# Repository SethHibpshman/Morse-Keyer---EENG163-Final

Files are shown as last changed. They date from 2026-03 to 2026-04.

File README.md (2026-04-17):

# Iambic Morse Keyer & Trainer

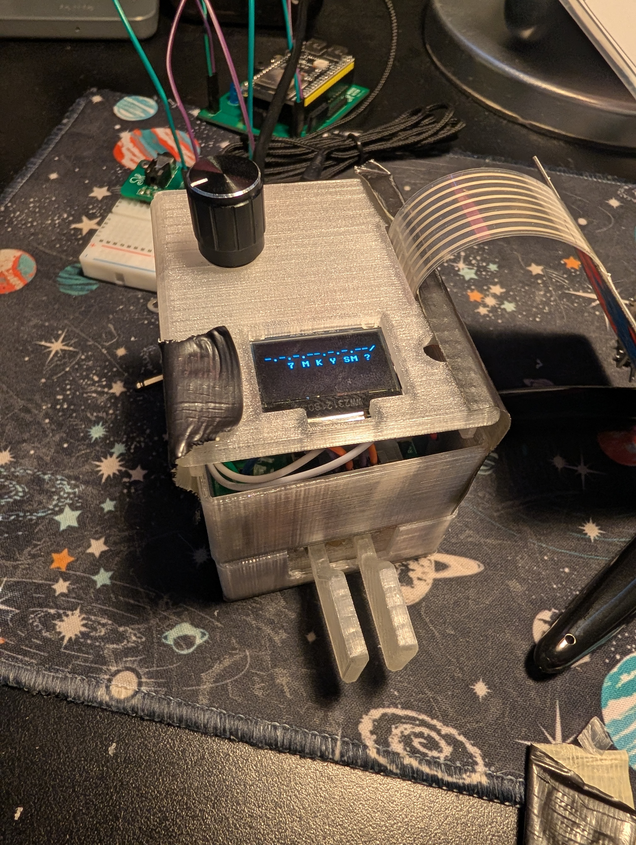
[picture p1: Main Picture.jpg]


A standalone, feature-rich Morse code keyer and trainer built on the ESP32-S3 running MicroPython. Designed as a hands-on embedded systems project covering real-time signal generation, hardware input handling, OLED display, settings menus, multi-mode keying, automatic decoding, and inter-device communication.

## Demo Video

See it [here](https://youtu.be/7UfE0N1uJJo)!

## Features

- **Four keying modes** — Iambic A, Iambic B, Ultimatic, and Straight Key
- **Real-time morse decoding** — automatically decodes keyed input to text on the OLED
- **Rotary encoder settings menu** — scroll and edit WPM, volume, LED, decoding toggle, and keying mode
- **Keyboard Replay Mode** — T9-style multi-tap keypad input encodes text to morse and plays it back
- **Automatic letter and word spacing** — gap detection scales with WPM setting
- **Sleep mode with screensaver** — bouncing logo after 60 seconds of inactivity
- **Boot screen** — typewriter-style startup sequence
- **Debug mode** — live paddle state, encoder pins, keypad input, and memory readout
- **UART communication** — transmits morse content to an STM32 relay display over serial

## Hardware

| Component | Details |
|---|---|
| Microcontroller | ESP32-S3 |
| Display | SSD1306 128x64 OLED (SoftI2C) |
| Paddles | 2x momentary buttons (Dit / Dah) |
| Keypad | 4x4 membrane matrix keypad |
| Rotary Encoder | CLK, DT, SW with long-press menu activation |
| Buzzer | Piezo PWM buzzer |
| LED | Single external indicator LED |
| Communication | UART1 to STM32 relay at 115200 baud |

## Pin Mapping

| Pin | Function |
|---|---|
| 7 | Dit paddle |
| 16 | Dah paddle |
| 38 | Buzzer (PWM) |
| 1 | External LED |
| 4 | Rotary CLK |
| 47 | Rotary DT |
| 45 | Rotary SW |
| 46 | OLED SCL |
| 8 | OLED SDA |
| 17 | UART TX |
| 18 | UART RX |
| 5, 6, 15, 17 | Keypad rows |
| 18, 2, 39, 40 | Keypad columns |

## PCB Design

Designed in KiCad. Project files available in [`/PCB Design - KiCad Program/ESP32 Board`](PCB%20Design%20-%20KiCad%20Program/ESP32%20Board).

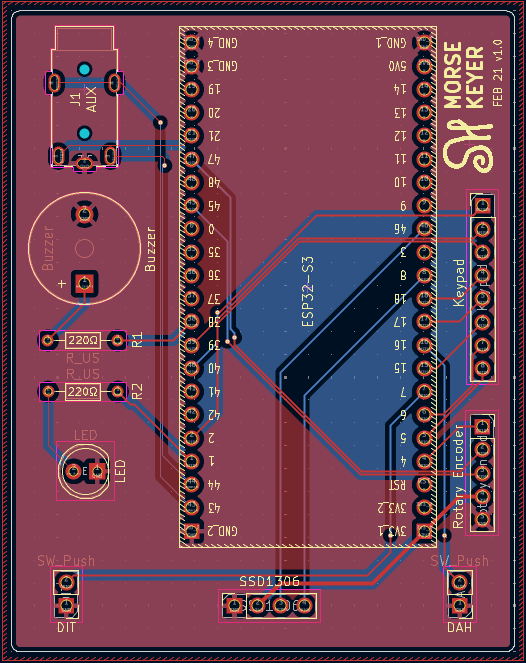
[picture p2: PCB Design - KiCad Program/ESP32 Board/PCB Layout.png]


## Software

Written entirely in **MicroPython**.

**Dependencies:**
- `ssd1306` — OLED driver
- `gfx` — OLED graphics primitives
- `keypad` — 4x4 matrix keypad driver
- `urandom` — screensaver randomization

## Project Structure

```
main.py          # Full application — hardware init, all functions, main loop
```

## Settings Menu

Hold the rotary encoder button for 2 seconds to open the settings menu. Short press to enter edit mode on a selected item. Rotate to scroll or adjust values.

| Setting | Options |
|---|---|
| Mode | Sandbox, Training, Keyboard Replay, Telegraph, Debug |
| Keying Mode | Iambic A, Iambic B, Ultimatic, Straight Key |
| Volume | 0 – 10 |
| LED | Enabled / Disabled |
| Decoding | Enabled / Disabled |
| About | Scrolling credits page |
| Reset | Hard resets the device |

## Keying Modes

| Mode | Behavior |
|---|---|
| **Iambic A** | Alternates dit/dah while both paddles held; stops on release |
| **Iambic B** | Same as A but sends one extra element after both paddles are released |
| **Ultimatic** | Last-pressed paddle wins when both are held simultaneously |
| **Straight Key** | Either paddle held produces a continuous tone |

## Morse Decoding

Gap detection runs automatically. After a paddle idle period equal to 3x the dit duration, a letter space is inserted and the last morse sequence is decoded. After 7x the dit duration, the space is upgraded to a word break. All thresholds scale with the live WPM setting.

## Keyboard Replay Mode

Enter text using the 4x4 keypad with T9-style multi-tap input (phone keyboard layout). The device encodes the typed text to morse in real time and displays it on the OLED. Press **B** to play the encoded sequence through the buzzer.

| Key | Control Action |
|---|---|
| A | Backspace |
| B | Play current text as morse |

## UART / STM32 Integration

In Telegraph mode, the device transmits the current morse string over UART1 as a UTF-8 newline-terminated message on each loop tick. A companion STM32 device running a separate display driver receives and renders the last 20 characters on an ILI9341 LCD.

## Cost

| Item | Qty | Unit | Total |
| --- | --- | --- | --- |
| ESP32-S3 Dev Board | 1 | $12.00 | $12.00 |
| Push Buttons (momentary) | 3 | $0.05  | $0.15 |
| Piezo Buzzer | 1 | $1.00  | $1.00 |
| LED | 1 | $0.03  | $0.03 |
| Resistors, wires, protoboard | — | — | $5.00 |
| SSD1306 OLED 128x64 | 1 | $3.00  | $3.00 |
| Rotary Encoder | 1 | $3.00  | $3.00 |
| 4x4 Membrane Keypad | 1 | $5.00  | $5.00 |
| PCBs (x1) | 1 | — | $5.00 |
| 3D-printed enclosure | 1 | — | $0.00 |
| STM32 Microcontroller (borrowed) | 1 | $0.00  | $0.00 |
| Aux ports / cables | — | — | $13.00 |
| 2nd ESP32 node (full duplicate)  | — | — | $29.13 |
| Microphone / analog input | 1 | $3.00  | $3.00 |
| Misc analog sensors | 1 | $2.00  | $2.00 |
| **Hardware Total** | | | **$81.34** |
| Software | — | — | $0.00 |
| Tools | — | — | $0 – $30 |
| **Grand Total** | | | **~$81 – $111** |

> **Notes:**
> - Unit costs reflect bulk purchasing; individual retail prices can be significantly higher.
> - Some components were salvaged or borrowed; actual cost may be lower.
> - 3D printing assumes university or personal printer access. Outsourced printing would add to the total.
> - PCB cost assumes overseas fabrication. Any revision spins add another ~$15 per run.
## Author

**Seth Hibpshman**
Student of Electrical Engineering — Eastern Washington University
EENG 163: Introduction to Embedded Systems

## License

GNU General Public License v3.0

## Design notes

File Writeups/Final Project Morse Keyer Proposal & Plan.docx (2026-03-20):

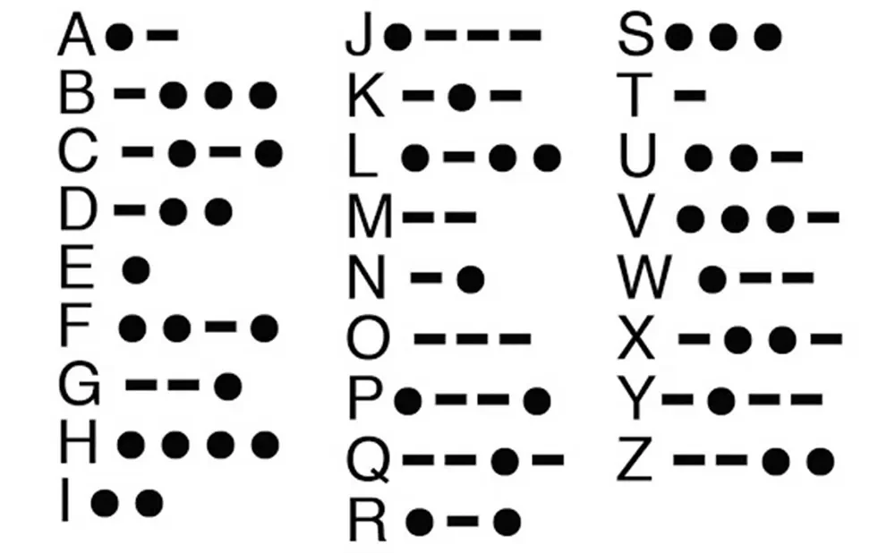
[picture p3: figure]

Iambic Morse Keyer and Trainer | Overview A standalone embedded device that generates accurate iambic Morse code and helps users learn and practice Morse through adjustable speed control, on-screen feedback, and interactive training and decoding modes. Seth Hibpshman EENG 163-001

# Iambic Morse Keyer and Trainer: Project Proposal

A hands-on embedded systems project focused on designing and programming a standalone iambic Morse code keyer that provides real-time feedback and basic training modes to reinforce timing, input handling, and user interaction fundamentals.

Seth A. Hibpshman

Student of Electrical Engineering

Eastern Washington University

EENG 163: Introduction to Embedded Systems

Draft #2

February 16, 2026

The cover image is provided by: Connie on retvis.com (https://www.retevis.com/blog/how-to-learn-morse-code)

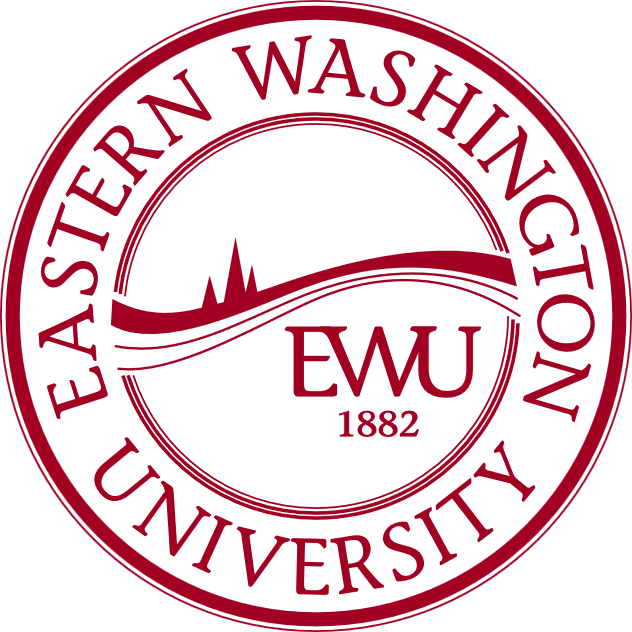
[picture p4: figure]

## List of Figures

## List of Tables

## Acronyms Used

Computer Aided Design

(CAD) 6

Eastern Washington University

(EWU) 10

Electrically Erasable Programmable Read-Only Memory

(EEPROM) 4

Input/Output

(I/O) 1

Inter-Integrated Circuit

(I2C) 2

Light-Emitting Diode

(LED) 1

Organic Light Emitting Diode

(OLED) 2

Over-the-Air

(OTA) 8

Printed Circuit Board

(PCB) 2

Universal Asynchronous Receiver-Transmitter

(UART) 7

Universal Serial Bus

(USB) 12

Words-per-Minute

(WPM) 3

# Project Background

This section attempts to provide personal insight into the team members’ thoughts on the project. Below is the testimonial of project lead: Seth Hibpshman.

## What is the reason behind this project?

“The reason behind this project is to explore microcontrollers and their applications using MicroPython in the backend. A Morse Keyer has a lot of timing elements, external peripherals, potential decoding applications, UI design, and networking potential. These are a variety of tasks that can be explored with embedded systems.”

## Why did you choose this project?

“I initially played around with a few ideas for a project. I wanted to do something I didn’t understand, and something that was complex enough for it to be hard for someone to replicate my work. Some of the initial ideas I played around with didn’t seem like they could challenge me as an Electrical & Computer Engineer, so I continued my research. The easiest way I could think of to fulfill my goals of the project (challenging & unique) was to increase the complexity. When breaking down concepts of Electrical Engineering, I also find it helpful to go back to history. Morse code and telegraph machines were some of the first long-distance communication devices. It was even more interesting how messages were sent with such limited signal transmission hardware. I thought this could be something interesting to replicate bottom up with a modern take on it.”

## Is there any special benefit to this project besides it being fun?

“Well, my immediate thoughts are that this is a learning experience. It’s an opportunity to learn more about concepts I learned at university and apply them in the field. It allows me to delve deeper into the sub-discipline of embedded systems. This helps me refine my interest in Electrical Engineering as I progress in my career.”

# Project Goals & Specification: By Version

Within the given timeframe and finances, the project team has outlined expectations for each project version. Each subsequent project version includes all the features from the last.

## Version 1.0 – Core Keyer Functionality

Version 1.0 establishes the foundation of the standalone iambic Morse keyer. It emphasizes stable, reliable operation, providing immediate auditory and visual feedback to the user while implementing proper iambic timing.

### Hardware & Input/Output (I/O)

- Design and build a functional standalone iambic Morse code keyer using a microcontroller.
- Implement three push buttons for “dit” and “dah” inputs. The additional button is to cycle through keying modes (Iambic A, Iambic B, Ultimatic, & Straight Key).
- Provide auditory feedback via a piezo buzzer.
- Provide visual feedback using a single Light-Emitting Diode (LED).

### Software & Functionality

- Implement correct iambic A morse timing for reliable keying.
- Research button debouncing methods to prevent button inputs to prevent false triggers.
- Apply modular software structure, including separate modules for input handling, timing control, output synchronization, and display man agement.

### Specifications

The Standalone Iambic Morse Keyer and Trainer shall function as a small, self-contained device approximately the size of a handheld gadget or small breadboard enclosure. The front panel will feature three push buttons clearly labeled for “dit” and “dah” input as well as the mode cycler button. Pressing these buttons will generate accurately timed Morse code elements according to standard iambic keying rules. This version supports multiple keyer modes, including Iambic A, Iambic B, Ultimatic, and Straight key operation, providing flexibility for different user preferences. A single LED will provide visual feedback for each signal, and a piezo buzzer will provide auditory confirmation.

Internally, the device will integrate an ESP32 microcontroller board, wiring, resistors, and buttons. Wires will be routed neatly on a prototyping breadboard as designed in Figure 1. The software will employ a modular structure separating input handling, timing control, display management, and output synchronization. The device will implement proper iambic A timing and incorporate debouncing methods to prevent false triggers. This version emphasizes stable, reliable operation with clean input/output feedback.

###### Figure 1. v1.0 Schematic Sketch (Hibpshman, 2026).

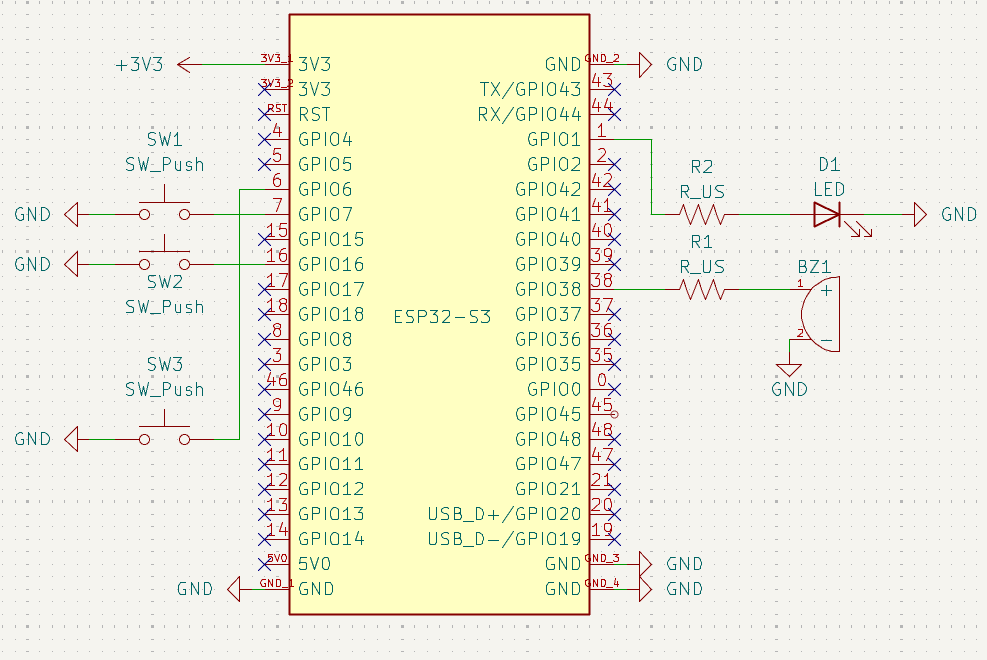
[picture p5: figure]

## Version 1.5 – Basic Display Integration

Version 1.5 introduces visual output for enhanced user interaction. The display allows users to see input sequences in real time, supporting further development of training and operational modes.

### Hardware & I/O

- SSD1306 128×64 Organic Light Emitting Diode (OLED) display integrated with the Inter-Integrated Circuit (I²C) protocol.

### Software & Functionality

- Display current keying mode.
- Show keyed dits (periods) and dahs (dashes).
- Display hardcoded Words-per-Minute (WPM) for reference.

### Specifications

This version extends Version 1.0 by visually representing Morse input and mode information on the OLED screen; dits will displayed as a period and dahs will be displayed as a dash as it is keyed. Wiring of the OLED screen can be seen in Figure 2. Users can track their keying and self-monitor performance, while the system maintains the same input handling, timing, and feedback mechanisms from the core version.

###### Figure 2. v1.5 Schematic Sketch (Hibpshman, 2026).

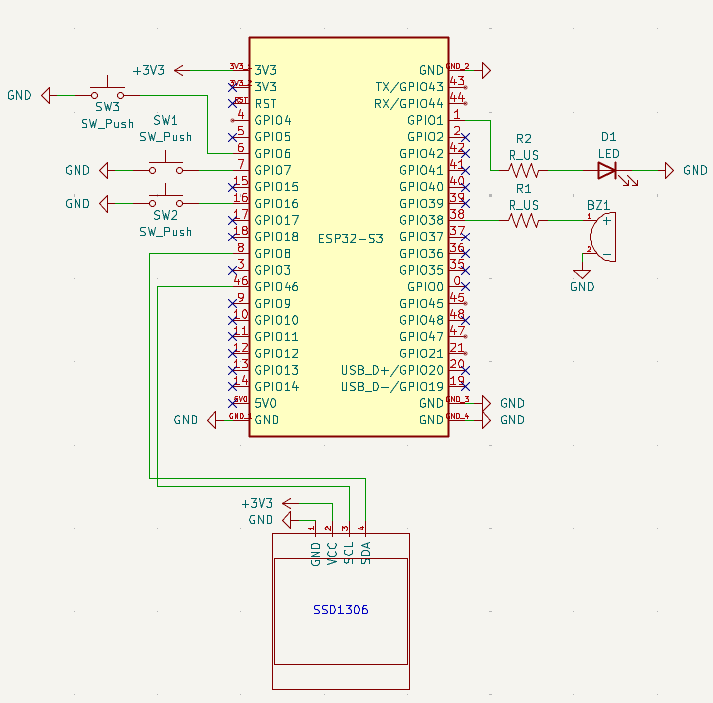
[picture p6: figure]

## Version 2.0 – User Interface Enhancement: Settings Menu, Navigation, and Rotary Encoder

Version 2.0 adds user input through configurability, enabling control over operational parameters through a navigable menu. The rotary encoder interface provides intuitive interaction while preserving reliable signal generation.

### Hardware & I/O

- Rotary encoder for user input for menu navigation and parameter adjustment.

### Software & Functionality

- On-device menu system with mode-specific sub-settings.
- Adjustable parameters including tone frequency, WPM, and buzzer volume.
- Persistent storage of user settings in flash memory.
- Sleep mode and screen saver for energy efficiency.

### Specifications

The integrated menu system allows the user to configure keyer behavior without sacrificing screen real estate. The rotary encoder can be held for two seconds, which will then display a settings menu. This menu has more items that will fit on the height of the screen, so scrolling was implemented. Displayed information includes active behavioral mode (to be implemented), keying input mode (Iambic A, B, Ultimatic, Straight Key), volume (0-10), LED enabled Boolean (Enabled, Disabled), morse decoding Boolean, scrollable about page (credits, sources, etc.), and device reset button. The rotary encoder is to be implemented as seen in Figure 3. Overall the settings menu allows a much higher configuration ability through the use of menus and scrolling.

Use of Electrically Erasable Programmable Read-Only Memory (EEPROM) ensures that preferences persist between sessions, while sleep mode reduces power consumption; the sleep mode includes a screensaver for visual flair.

###### Figure 3. v2.0 Schematic Sketch (Hibpshman, 2026).

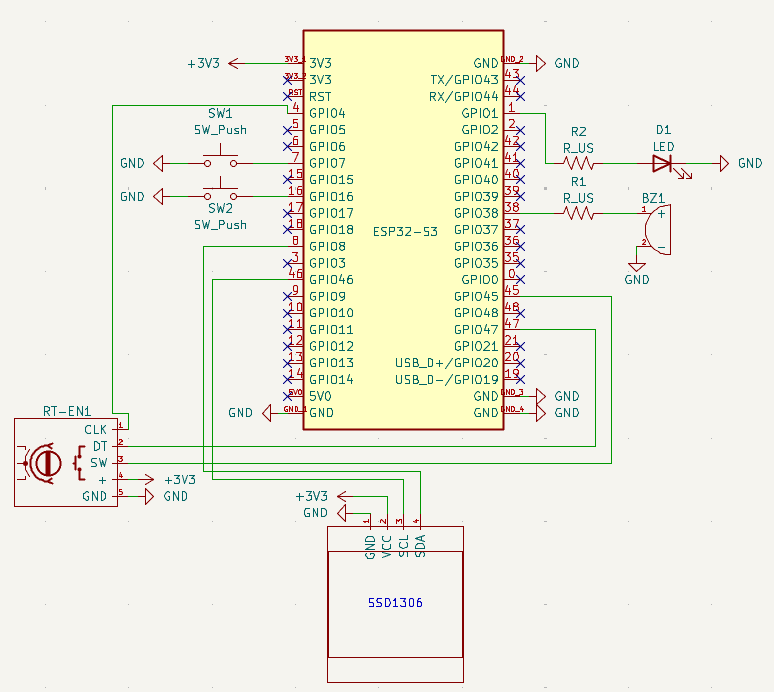
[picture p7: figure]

## Version 2.5 - Training & Replay Modes

Version 2.5 introduces educational and practice features to enhance skill development. Training and Replay Modes allow users to practice accuracy, speed, and sequence recall.

### Hardware & I/O

- 4×4 membrane keypad for custom alphabetic entry in Replay Mode.

### Software & Functionality

- Training Modes: recall, replay, and pangram. Each mode will provide immediate feedback on correctness, and track session accuracy & scoring.
- Recall mode prompts the user for random letters, words, or short sentences.
- Alphabet and pangram challenges, including standard pangrams such as “The quick brown fox jumps over the lazy dog.”
- Replay Mode to reproduce custom sentences in Morse code.
- Dynamic WPM tracking over short intervals for performance evaluation.

### Specifications

In the settings, the behavioral mode can be adjusted to either Sandbox (default mode) or Training. If Training is selected, then there will be dynamically visual sub-settings for that mode in the settings menu. The sub-settings include the training mode such as Recall, Replay, and Pangram.

The Recall mode randomly generates either individual letters, words, or sentences for the user to key back. The mode will then give feedback on correctness and speed. Similar to recall, pangram generates sentences for the user to key back, but it will include every letter in the alphabet, like the popular pangram “The quick brown fox jumps over the lazy dog”. Replay mode makes use of the 4×4 membrane keypad for alphabetic input. The input is in the style of an older phone where there are multiple letters per button, and pressing a button multiple times will change the current letter being typed.

Last, the dynamic WPM can be enabled in any training mode or Sandbox mode. It will track the user’s WPM over the last short period of time and display the live number on-screen.

## Version 3.0 – PCB & Enclosure

Version 3.0 transitions the project to a finalized hardware platform with integrated PCB design and a protective enclosure, enhancing reliability, portability, and overall presentation.

### Hardware & I/O

- Custom PCB integrating wiring, resistors, buttons, display, LEDs, buzzer, and rotary encoder.
- 3D-printed or custom enclosure with dedicated openings for paddles, display, and inputs.

### Specifications

The device becomes a fully standalone unit suitable for desktop or portable use. The PCB ensures firm wiring connections and reduces risk of mechanical stress on wiring. All core features, functionality, and training modes remain intact and fully operational.

The design will be created in KiCad, the open-source PCB Computer Aided Design (CAD) tool. This includes potentially custom symbols, footprints, and layout of the PCB and schematic. The design can then be sent to an overseas manufacturer for reduced build costs; because of the shipping time and potential iterations involved in PCB design, this will be worked on prior to the implementation of all features.

3D-printed designs are modeled in AutoCAD, with the educational license for access. These designs can then be printed with university printers that can be found across campus.

## Version 4.0 – Communications Network Mode & STM32 Integration as a Communications Relay

Version 4.0 adds networked communication capabilities, allowing the keyer to transmit and receive messages to a network of devices. This is implemented through a star topology where all devices (ESP32 nodes) and connected to a central hub/office (STM32 router). This enables multi-device integration and message relaying across a short distance.

### Hardware & I/O

- STM32 microcontroller for communication relay.
- Auxiliary ports and cabling for ESP32–STM32 connection.

### Software & Functionality

- Universal Asynchronous Receiver-Transmitter (UART) based communication between ESP32 and STM32.
- Mode selection for transmission, with target selection (office or another ESP32).
- Real-time message relaying across connected devices.

### Specifications

This version extends the system to support distributed communication. Users can select targets for transmission, and messages are relayed in real time while preserving keyer functionality and display features. Each device will include an 3.5mm auxiliary jack to accommodate a 2-3 wire communication protocol between devices (Figure 4).

The ‘Transmission’ mode can be selected in the settings. The sub-setting of ‘Destination’ then becomes available. The user can either choose to transmit to the whole network or a specific device. Feedback will be provided if successfully connected, line busy, or no nodes available.

###### Figure 4. v4.0 Schematic Sketch (Hibpshman, 2026).

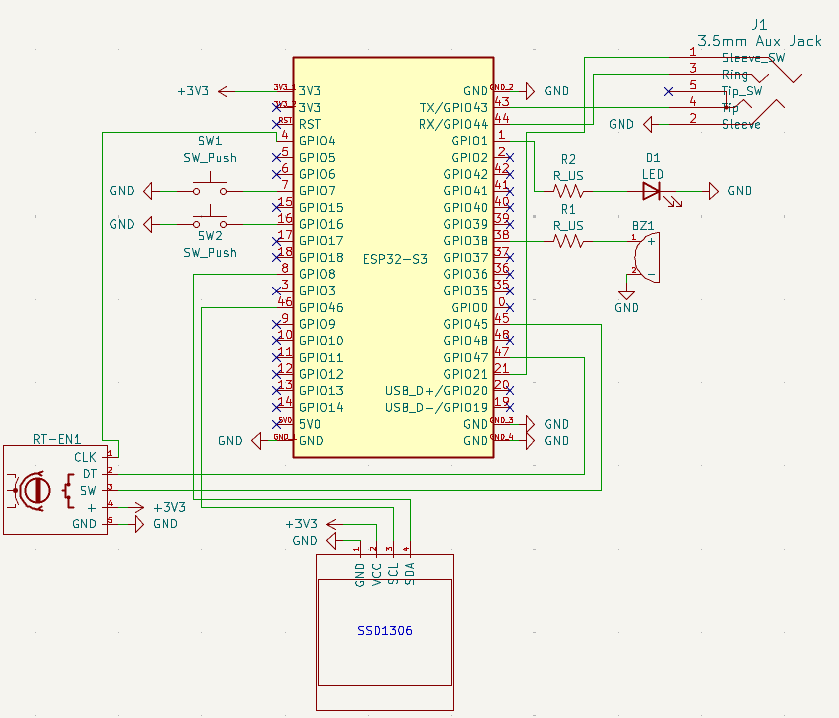
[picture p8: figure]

## Version 5.0 - Over-the-Air (OTA) Transmission/Decoding & Advanced Signal Processing

This ‘feature’ is more of an additional project within this project, so it takes the least priority of all goals. Version 5.0 introduces advanced analog input and Over-the-Air transmission/decoding capabilities, expanding the keyer into experimental communication and signal processing applications.

### Hardware & I/O

- Microphone or light-based analog input for alternative signal sources.
- Wi-Fi or Bluetooth module for OTA communication.

### Software & Functionality

- Analog preprocessing with thresholding and debouncing.
- Timing estimation using ON/OFF duration histograms.
- Noise filtering and symbol extraction to identify dits and dahs.
- Advanced digital signal processing for source-agnostic decoding, including word segmentation and error correction.

### Specifications

The system can now receive and process Morse code from a variety of analog sources. OTA transmission allows messages to be shared wirelessly, while signal processing ensures reliable reconstruction of text even in the presence of noise or irregular timing. This version represents the most advanced stage, combining all previous features with experimental communication and decoding capabilities.

Again, this is highly experimental. Device nodes can transmit data through the morse flashing of either an LED or soundwaves. The receiver node will include a corresponding sensor such as a sound sensor or photo-resistor. These analog values collected can then be sent through the interpretation and reconstruction algorithm detailed in Figure 5.

###### Figure 5. Digital Signal Processing: Algorithmic Flow Chart (Hibpshman, 2026).

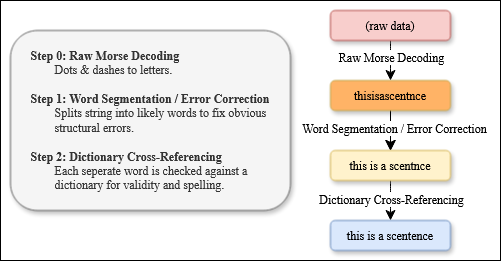
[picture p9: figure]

# Expected Financial Costs

This section aims to provide an analysis of the potential costs associated with this project. This includes the cost of the employment of labor, hardware purchases, and software usages.

## Labor

Most of the labor for this project is subsidized by Eastern Washington University (EWU) student(s) on a volunteer basis and thus minimal labor costs. Labor costs are not billed but should be noted in terms of hours and effort.

Cumulative total labor cost estimate: $0

## Hardware

It is worth noting that bulk part purchasing costs are considered. One would not see such low prices for individual components unless buying 50-100 at once; the engineering team is incurring additional start-up costs. Moreover, hardware costs that can be salvaged or borrowed is also not considered; so there is potential for cost savings.

The following table summarizes the expected hardware components and associated costs for the project. Each part is noted in which version it is needed.

###### Table 1. Hardware Financial Breakdown by Part & Purpose (Hibpshman, 2026).

Version | Category / Item | Quantity | Unit Cost | Total Cost | Notes
v1.0 – Core Keyer | ESP32-S3 Dev Board | 1 | $12 | $12 | Core processor
| Push Buttons (momentary) | 3 | $0.05 | $0.15 | Dit / Dah inputs & mode switcher
| Piezo Buzzer | 1 | $1 | $1 | Auditory feedback
| LED (single) | 1 | $0.03 | $0.03 | Visual feedback
| Resistors, wires, prototyping board | N/A | $5 | $5 | Mounting and connections
| OLED 128×64 I²C | 1 | $3 | $3 | WPM, mode display
| Subtotal v1.0 | | | $21.13 | Core keyer hardware only
v1.5 – Display Integration | OLED display already included | 1 | $0 | $0 | Already in v1.0
| Subtotal v1.5 | | | $21.13 | No additional cost; software integration only
v2.0 – Menu / Rotary Encoder | Rotary Encoder with switch | 1 | $3 | $3 | Menu navigation
| Subtotal v2.0 | | | $24.13 | Adds menu/navigation hardware
v2.5 – Training / Replay Modes | 3×3 Membrane Keypad | 1 | $5 | $5 | Replay Mode input
| Subtotal v2.5 | | | $29.13 | Hardware for custom input
v3.0 – PCB & Enclosure | Plastic / 3D-printed case | 1 | $0 | $0 | Enclosure for PCB and components
| PCBs | 3 | | $15 | Neat wiring & stability
| Subtotal v3.0 | | | $44.13 | No additional cost if 3D print available
v4.0 – STM32 & Comm Relay | STM32 Microcontroller | 1 | $10 | $10 | For communication relay experiments
| Aux ports / cables | 1 | $2 | $13 | UART / auxiliary connections
| A copy of all prior parts. | | | $29.13 | A 2nd ESP device on the communications network. (Didn’t include cost of 2nd PCB)
| Subtotal v4.0 | | | $96.26 | Experimental communication hardware
v5.0 – Analog / OTA / DSP | Microphone / analog input | 1 | $3 | $3 | OTA / audio decoding experiments
| Miscellaneous analog sensors | 1 | $2 | $2 | Light or threshold input
| Subtotal v5.0 | | | $101.26 | Advanced input/processing hardware

Cumulative total hardware cost estimate: $101.26

## Software

All software required for the project will be open-source or free for educational use:

- Notepad++ & PyCharm for firmware development.
- Free Python libraries for OLED display, rotary encoder, and buzzer output.
- KiCad for schematic and PCB design.

Cumulative total software cost estimate: $0

## Tools Needed

Completion of the project will require access to the following tools:

- Soldering iron and solder
- Multimeter for testing electrical connections
- Power supply or Universal Serial Bus (USB) power source for the microcontroller
- Optional 3D printer or laser cutter if producing a custom enclosure
- Computer for programming and testing the microcontroller

Some tools may already be available in a university lab environment; otherwise, small purchases or lab access may be necessary.

Cumulative total tools needed cost estimate: $0-30

# Possible Issues & Risks

The project involves multiple hardware and software subsystems that introduce technical and scheduling risks. The following items identify potential issues and mitigation strategies.

## Timing Accuracy and Real-Time Constraints

Morse keying requires precise timing for dits, dahs, and inter-element spacing. Display updates, menu navigation, or background processing could introduce latency and disrupt signal accuracy. This risk will be mitigated by separating timing control from user interface tasks and prioritizing real-time signal generation.

## Button Debouncing and Input Reliability

Mechanical push buttons and keypads may generate false triggers due to contact bounce. Improper debouncing could lead to incorrect symbol generation or menu navigation errors. Software debouncing and validation through oscilloscope or serial timing measurements will be used to ensure stable input handling.

## Flash Memory Wear and Data Integrity

Frequent writing of settings to flash memory may reduce memory lifespan or lead to corrupted configuration data. Writes will be limited to events where settings are changed, and default recovery values will be implemented in case of read failure.

## Power Consumption and Sleep Mode Behavior

Improper sleep implementation may cause the device to fail to wake reliably or may not provide meaningful power savings. Power states will be tested under multiple usage scenarios to ensure correct wake behavior and stable operation.

## User Interface Complexity

The rotary encoder menu system and mode-dependent sub-settings introduce additional software complexity. There is a risk of navigation errors, inaccessible settings, or state conflicts between modes. This will be addressed through structured state management and incremental testing of each menu layer.

## Keypad Multi-Tap Input Ambiguity

Replay Mode uses multi-tap character selection, which introduces timing thresholds for character confirmation. Incorrect timing windows may lead to unintended character selection. Adjustable timeout parameters and visual confirmation of the current character will reduce this risk.

## PCB Design Errors

Schematic or footprint mistakes may result in incorrect pin mapping, insufficient trace clearance, or power routing issues. Design rule checks, peer review, and prototype testing on a breadboard prior to fabrication will reduce the likelihood of costly board revisions.

## Mechanical Fit and Enclosure Constraints

Improper enclosure dimensions may obstruct connectors, displays, or input devices. A prototype enclosure will be test-fitted using cardboard or low-cost prints before final fabrication.

## UART Communication Synchronization

Version 4.0 introduces inter-device communication through UART. Mismatched baud rates, framing errors, or buffer overruns could interrupt message relaying. Communication protocols will include handshake validation and error detection to ensure reliable transmission.

## Network Topology Scaling

The star topology using a central relay may become a bottleneck if multiple nodes transmit simultaneously. A basic queueing or busy-state signaling mechanism will be implemented to prevent data collisions. This is also limited by the number of UART ports on the STM32 model used.

## Analog Signal Noise in OTA Experiments

Microphone and light-based decoding are susceptible to environmental noise and inconsistent signal amplitude. Threshold calibration, filtering, and histogram-based timing analysis will be used to improve symbol detection reliability.

## Project Scope and Time Constraints

Later versions, particularly PCB fabrication, STM32 integration, and OTA decoding, depend on earlier milestones. Delays in hardware delivery or debugging could limit the ability to complete advanced features. The versioned structure allows the project to remain functional even if stretch goals are deferred.

## Component Availability and Shipping Delays

PCB fabrication and certain components may require overseas ordering with variable shipping times. Early ordering and maintaining breadboard-based functionality as a fallback will mitigate schedule impact.

## Tool and Lab Access

Limited access to soldering equipment, multimeters, or 3D printers may delay hardware integration. Backup plans include scheduling lab time in advance and maintaining modular test configurations.

# Work Breakdown Structure (Project Milestones)

The team has sketched out project milestones that they expect to reach once the project is approved by the client. If goals are met quicker than expected, the team will immediately start working on the next milestone. If all milestones are completed, the team shall work on the stretch goals outlined.

The client is adamant about the integration of the STM32 microcontroller into the project. This will be integrated in version 4.0; version 4.0 will be prioritized over other milestones as the deadline approaches.

Firm project milestones can be negotiated with the client, but the timeline will remain flexible as the labor power of the project is completely comprised of university students.

## I. Version 1.0 – Core Keyer Functionality – 01/30/26

Implement the foundational standalone iambic Morse keyer using three push buttons for “dit,” “dah,” and mode cycling. Ensure accurate timing for Iambic A, Iambic B, Ultimatic, and Straight key modes. Provide synchronized auditory feedback through the piezo buzzer and visual feedback using a single LED. Implement reliable button debouncing and verify stable real-time signal generation on a prototyping platform.

## II. Version 1.5 – Basic Display Integration – 02/06/26

Integrate the SSD1306 128×64 OLED via I²C. Display keyed dits and dahs in real time along with the active keying mode and a fixed WPM reference. Validate that display updates do not interfere with timing accuracy or output synchronization. Confirm stable operation with continuous input and output activity.

## III. Version 2.0 – User Interface Enhancement: Settings Menu, Navigation, and Rotary Encoder – 02/13/26

Implement a rotary encoder-driven menu system with scrolling support and long-press activation. Add adjustable parameters including WPM, tone frequency, buzzer volume, LED enable state, and decoding toggle. Implement persistent storage of settings in flash memory and verify correct restoration on boot. Add sleep mode with a screen saver and confirm reduced power behavior without disrupting wake functionality.

## IV. Version 2.5 – Training & Replay Modes – 02/20/26

Develop Training Modes including Recall, Alphabet, Pangram, and Replay. Integrate the 4×4 membrane keypad for multi-letter input in Replay Mode using multi-tap character selection. Implement real-time correctness feedback, session scoring, and dynamic WPM tracking over short intervals. Add mode-specific sub-settings that appear only when the corresponding behavioral mode is active. Validate accurate performance evaluation and responsive user interaction.

## V. Version 3.0 – PCB & Enclosure – 02/27/26

Design the complete schematic and PCB layout in KiCad, including custom symbols and footprints as required. Route all components for a compact, reliable standalone board. Submit the PCB for fabrication and begin enclosure design in AutoCAD with cutouts for paddles, display, encoder, keypad, LED, buzzer, and auxiliary ports. Assemble and test the fabricated PCB to confirm full functionality of all previously implemented features.

## VI. Version 4.0 – Communications Network Mode & STM32 Integration – 03/06/26

Integrate STM32 as a central communication relay using UART connections through auxiliary ports. Implement Transmission Mode with destination selection (specific node or broadcast). Provide connection status feedback including successful link, line busy, and no-node conditions. Validate real-time message relaying between devices while maintaining full keyer and display functionality.

## VII. Version 5.0 – Over-the-Air (OTA) Transmission/Decoding & Advanced Signal Processing – (Stretch)

Begin experimental implementation of analog signal reception using microphone and light-based sensors. Develop preprocessing stages including thresholding, debouncing, ON/OFF duration measurement, noise filtering, and dit/dah classification. Implement basic OTA transmission via LED or audio output and reconstruct decoded text using timing-based algorithms. Explore higher-level processing such as word segmentation and error correction as time permits.

# References

Hibpshman, S. (2026, January). Cheney, Washington, United States of America.

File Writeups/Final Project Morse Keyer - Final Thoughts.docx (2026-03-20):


Iambic Morse Keyer and Trainer | Overview A standalone embedded device that generates accurate iambic Morse code and helps users learn and practice Morse through adjustable speed control, on-screen feedback, and interactive training and decoding modes. Seth Hibpshman EENG 163-001

# Iambic Morse Keyer and Trainer: Project Proposal

A hands-on embedded systems project focused on designing and programming a standalone iambic Morse code keyer that provides real-time feedback and basic training modes to reinforce timing, input handling, and user interaction fundamentals.

Seth A. Hibpshman

Student of Electrical Engineering

Eastern Washington University

EENG 163: Introduction to Embedded Systems

Final Project Thoughts

March 18, 2026

The cover image is provided by: Connie on retvis.com (https://www.retevis.com/blog/how-to-learn-morse-code)

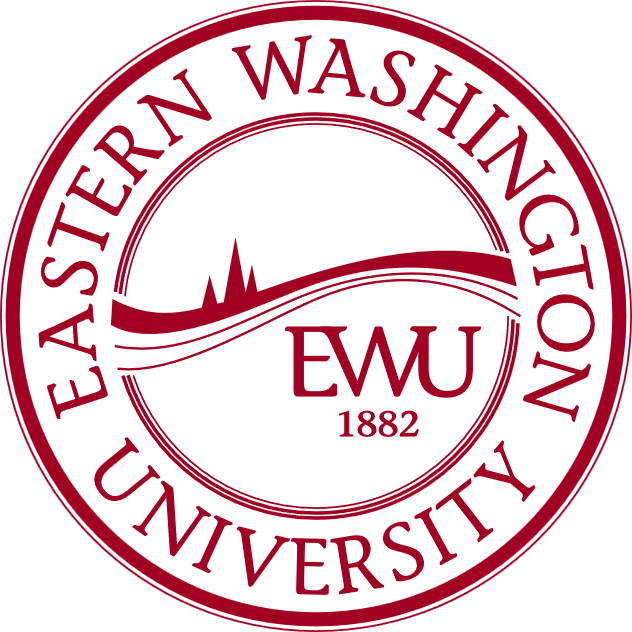
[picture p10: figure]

# Project Goals & Outcomes

The goal of this project was to design and build a functional morse code keyer and trainer using an ESP32-S3 microcontroller running MicroPython. The core objective was to create a device that could key morse code through paddle inputs, decode it in real time, and display output on an OLED screen. This goal was fully met.

Beyond the core requirement, the project grew significantly in scope. A rotary encoder-driven settings menu was implemented with live-adjustable parameters including WPM, volume, keying mode, LED feedback, and decoding toggle. Four distinct keying modes were developed: Iambic A, Iambic B, Ultimatic, and Straight Key. A 4x4 matrix keypad was integrated to support a Keyboard Replay Mode, allowing alphabetic text entry via multi-tap T9 input that is encoded to morse and played back through the buzzer. Additional features included automatic morse decoding displayed on the OLED, a sleep mode with a bouncing logo screensaver, and a typewriter-style boot screen. The final device was also housed in a custom enclosure and custom manufactured Printed Circuit Board.

# Future Improvements

Several improvements would strengthen the device in a future revision. The most impactful would be a proper Training Mode with structured exercises, prompting the user with a letter or word and scoring their keyed response. The groundwork for this mode exists in the codebase but the scoring logic was not implemented within the project timeline.

Additionally, the current morse decoding relies entirely on gap timing, which means imprecise keying or slight timing drift can produce incorrect letter breaks. A more robust signal processing approach, such as adaptive timing based on the user's average dit length, would significantly improve decoding accuracy at varying skill levels. Persistent settings storage using non-volatile memory would also be a valuable addition, as all settings currently reset to defaults on power cycle.

# Project Limitations

The primary hardware limitation encountered was the refresh rate of the SSD1306 OLED display. At the I2C speeds available on the ESP32-S3 with a software I2C implementation, full screen redraws produced visible flicker during active keying. This was mitigated by minimizing the number of pixels redrawn per update, only clearing and redrawing the regions of the screen that changed rather than calling a full screen clear each time.

Memory was also a consideration on the microcontroller. MicroPython's overhead on the ESP32-S3 leaves a limited heap for application data, which influenced decisions around string handling and buffer management. The morse content string grows unbounded during a session, though in practice the display only ever shows the last 16 characters, so this was an acceptable tradeoff for the project scope.

# Challenges & Solutions

The most technically challenging aspect of the project was implementing reliable gap detection for automatic letter and word spacing. Morse code timing is inherently relative, as the gap between two elements depends on the operator's speed, so a fixed threshold in milliseconds would fail at different WPM settings. The solution was to derive all timing thresholds dynamically from the dit duration, which itself is calculated from the live WPM setting. This meant letter breaks, word breaks, and inter-element gaps all scale correctly as the user adjusts speed.

Implementing Iambic B keying mode also required careful state management. Iambic B requires the keyer to send one additional element after both paddles are released, remembering which element was sent last. This was solved by tracking a "both held" flag across loop iterations and firing one extra element on the cycle after release.

The settings menu required significant architectural work to implement cleanly. Making the menu index-agnostic, so that adding or reordering items would not break the logic, involved abstracting menu items into a list of tuples and driving all selection, scrolling, and editing behavior from that single data structure.

# Key Resources

The primary software resources used in this project were the MicroPython documentation, the SSD1306 and GFX libraries for OLED rendering, and the official Morse code symbol reference from Wikipedia. Hardware datasheets for the ESP32-S3 were referenced during pin assignment and peripheral configuration. PyCharm and Thonny were used as development environments throughout the project.

# Project Reflection

The most satisfying aspect of this project was watching isolated components come together into a cohesive and genuinely usable device. Implementing a feature like Iambic B, which competitive morse operators rely on, and having it work correctly on custom hardware was a meaningful milestone.

The most challenging part, and the least enjoyable in the moment, was debugging timing-related issues. Because so much of the program depends on millisecond-accurate loop execution, any blocking call such as a slow OLED redraw would throw off keying feel and gap detection. Tracking down these interactions required careful instrumentation and rethinking how and when screen updates were triggered.

Overall the project was a strong balance of hardware and software work, and the open-ended scope allowed the device to grow well beyond a minimum viable product.

# Assignment Design Feedback

The open-ended nature of the final project assignment was well suited to this type of work. Being able to define the project goal independently allowed the scope to match personal interest, which drove significantly more effort than a prescribed assignment likely would have.

If the assignment were to be redesigned, one suggestion would be to require a brief scoping checkpoint partway through the project timeline. Several features were added late in development that, had they been planned earlier, would have influenced earlier architectural decisions. A midpoint design review would encourage students to think about extensibility before the codebase grows large enough that restructuring becomes costly.

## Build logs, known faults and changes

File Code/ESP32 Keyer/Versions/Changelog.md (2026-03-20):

# Morse Keyer & Trainer — Changelog

**Project:** ESP32-S3 Morse Keyer & Trainer
**Course:** EENG 163 — Final Project
**Total Logged Hours:** 53+

---

## v1.13.1
- Enhanced wake procedures on rotary encoder rotation
- Cleaned up memory usage display in debug mode

---

## v1.12.0
- Sleep mode after 60 seconds of inactivity
- Bouncing logo screensaver during sleep
- Typewriter-style boot screen on startup

---

## v1.11.0
- Added Debug Mode with live paddle state, encoder pins, keypad input, memory usage, and clock display

---

## v1.10.6 `+14 hrs`
- Keypad hardware integration
- Complete code overhaul to support multiple modes
- Keyboard Replay Mode: alphabetic keypad input with live morse encoding preview
- Key B plays the encoded morse string out loud with live decoding

---

## v1.10.5
- Decoding toggle setting now wired into program behavior
- Moved Keying Mode under Behavior heading in settings menu

---

## v1.10.4
- Reset option in settings menu now functional

---

## v1.10.3
- Scrollable about/credits page added to settings menu

---

## v1.10.2
- Section headings added to settings menu

---

## v1.10.1
- All settings menu values now drive program behavior (index-agnostic)

---

## v1.10.0 `+7 hrs`
- Full settings menu integration: volume and all settings now control live behavior
- Reworked how list-type settings (modes, keying modes) are applied

---

## v1.9.3
- Settings menu fully functional

---

## v1.9.2
- Fixed button release detection, long-hold vs short-hold edge cases

---

## v1.9.1
- Basic settings menu integration

---

## v1.9.0 `+4 hrs`
- Removed standalone mode button and mode display from OLED in preparation for settings menu

---

## Intermediary `+6 hrs`
- Rotary encoder testing and integration
- Enclosure design and build

---

## v1.8.0
- Integrated GFX graphics library for OLED drawing primitives

---

## v1.7.0
- Added `draw_right_aligned()` — morse content renders from the right edge so gaps are visible as text scrolls left
- Decoder now prints decoded letters to the OLED display in addition to decoding internally
- Decoder is called automatically before letter and word spaces are written

---

## v1.6.1
- Implemented basic morse decoding function

---

## v1.6.0 `+3 hrs`
- WPM-based timing formula added
- WPM displayed on OLED

---

## v1.5.1
- Code cleaned and reorganized, redundant code removed

---

## v1.5.0
- Tracks button release time in addition to press time
- Inserts letter space or word space (`/`) depending on idle duration

---

## v1.4.0 `+4 hrs`
- `gap_checker()` implemented: detects gaps between morse elements and classifies them as letter or word breaks
- Fixed OLED flicker caused by calling draw function without current content
- Timing variable names updated for clarity

---

## v1.3.2 `+3 hrs`
- Migrated to 128×64px OLED — UI updated to match
- Morse alphabet dictionary added
- Inter-symbol gap timing variable added

---

## v1.3.0
- Implemented Ultimatic keying mode
- Button state tracking: records when each paddle was first pressed and whether it is currently held

---

## v1.2.0
- Mode switching implemented via indexed list
- Removed `Straight Paddle` mode
- Fixed bug in Straight Key mode causing constant beeping
- Implemented Iambic B mode

---

## v1.1.0 `+7 hrs`
- Added keying mode selection
- Display updates to reflect active mode

---

## v1.0.1
- Removed redundant `last_d` initialization

---

## v1.0.0 `+7 hrs`
- Major code reorganization — modular structure established

---

## v0.3.0
- LED support for visual feedback
- Display shows only the last 16 characters of the morse string, keeping RAM usage bounded
- Removed shell dot/dash printout

---

## v0.2.0
- Remembers the last element sent — both-paddles-held now alternates based on which was pressed first rather than always starting with dit

---

## v0.1.0 `+5 hrs`
- Basic dit and dah output depending on which paddle is pressed
- Both paddles held produces alternating dit-dah pattern

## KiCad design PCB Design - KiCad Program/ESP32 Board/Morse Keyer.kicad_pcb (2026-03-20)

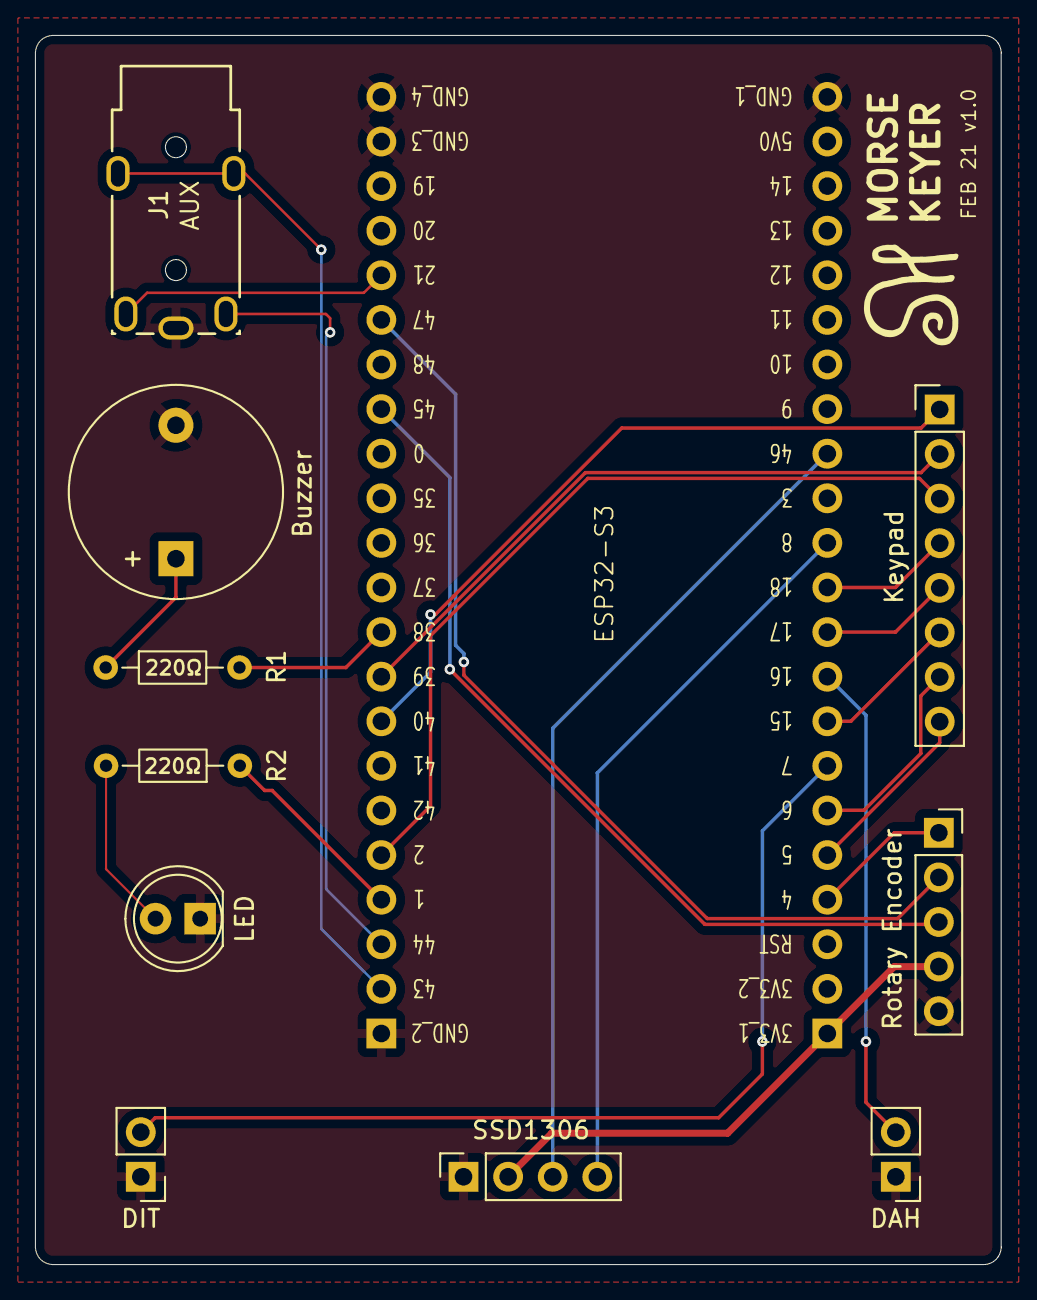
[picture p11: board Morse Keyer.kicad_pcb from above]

Board: 4 copper layers, 55.0 x 70.0 mm, 11 parts (0 on the bottom side), 24 nets.

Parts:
Buzzer: Buzzer_12x9.5RM7.6
DAH: SW_Push; PinHeader_1x02_P2.54mm_Vertical
DIT: SW_Push; PinHeader_1x02_P2.54mm_Vertical
ESP32-S3: ESP32-S3 Mount
J1: 3.5mm Aux Jack; 54-00174_TEN
Keypad: PinHeader_1x08_P2.54mm_Vertical
LED: LED; LED_D5.0mm
R1, R2: R_US; R_Axial_DIN0204_L3.6mm_D1.6mm_P7.62mm_Horizontal
Rotary Encoder: PinSocket_1x05_P2.54mm_Vertical
SSD1306: PinSocket_1x04_P2.54mm_Vertical

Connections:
+3V3: ESP32-S3.3V3_1 (3V3), Rotary Encoder.4 (+), SSD1306.2 (VCC)
/GPIO1: ESP32-S3.1 (GPIO1), R2.1
/GPIO2: ESP32-S3.2 (GPIO2), Keypad.3 (Col_2)
/GPIO4: ESP32-S3.4 (GPIO4), Rotary Encoder.1 (CLK)
/GPIO5: ESP32-S3.5 (GPIO5), Keypad.8 (Row_1)
/GPIO6: ESP32-S3.6 (GPIO6), Keypad.7 (Row_2)
/GPIO7: DIT.2, ESP32-S3.7 (GPIO7)
/GPIO8: ESP32-S3.8 (GPIO8), SSD1306.4 (SDA)
/GPIO15: ESP32-S3.15 (GPIO15), Keypad.6 (Row_3)
/GPIO16: DAH.2, ESP32-S3.16 (GPIO16)
/GPIO17: ESP32-S3.17 (GPIO17), Keypad.5 (Row_4)
/GPIO18: ESP32-S3.18 (GPIO18), Keypad.4 (Col_1)
/GPIO21: ESP32-S3.21 (GPIO21), J1.1 (Sleeve_SW)
/GPIO38: ESP32-S3.38 (GPIO38), R1.2
/GPIO39: ESP32-S3.39 (GPIO39), Keypad.2 (Col_3)
/GPIO40: ESP32-S3.40 (GPIO40), Keypad.1 (Col_4)
/GPIO45: ESP32-S3.45 (GPIO45), Rotary Encoder.3 (SW)
/GPIO46: ESP32-S3.46 (GPIO46), SSD1306.3 (SCL)
/GPIO47: ESP32-S3.47 (GPIO47), Rotary Encoder.2 (DT)
/RX/GPIO44: ESP32-S3.44 (RX/GPIO44), J1.3 (Ring)
/TX/GPIO43: ESP32-S3.43 (TX/GPIO43), J1.4 (Tip)
GND: Buzzer.2 (-), DAH.1, DIT.1, ESP32-S3.GND_1 (GND), ESP32-S3.GND_2 (GND), ESP32-S3.GND_3 (GND), ESP32-S3.GND_4 (GND), J1.2 (Sleeve), LED.1 (K), Rotary Encoder.5 (GND), SSD1306.1 (GND)
unnamed: Buzzer.1 (+), R1.1
unnamed: LED.2 (A), R2.2

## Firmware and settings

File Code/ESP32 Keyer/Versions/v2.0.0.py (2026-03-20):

"""
Morse Keyer & Trainer — ESP32-S3
=================================
A MicroPython-based morse code keyer and trainer. Handles paddle input,
buzzer output, OLED display, rotary encoder settings menu, UART TX,
and automatic morse decoding.

Hardware:
    - ESP32-S3 microcontroller (MicroPython)
    - SSD1306 128x64 OLED via SoftI2C
    - Buzzer on Pin 38
    - Dit paddle on Pin 7, Dah paddle on Pin 16
    - Rotary encoder: CLK=4, DT=47, SW=45
    - External LED on Pin 1
    - UART1 TX=17, RX=18 at 115200 baud

Classes:
    None — procedural style with grouped functions

Author: Seth Hibpshman
Course: EENG 163 Final Project
License: GNU GPL v3
"""

from machine import Pin, SoftI2C, PWM, reset, UART
import ssd1306
import gfx
from time import sleep, ticks_ms, ticks_diff
import gc
import urandom

# <><><><><><><><><><><><><><><><><><><><><><>
# SETUP
# <><><><><><><><><><><><><><><><><><><><><><>

# HARDWARE ##############################

# UART
uart = UART(1, baudrate=115200, tx=17, rx=18)
last_sent_morse = ""

# Buzzer
buz = PWM(Pin(38))
buz.freq(700)
buz.duty_u16(0)
buz_vol_list = [0, 500, 1200, 2500, 5000, 9000, 15000, 23000, 33000, 46000, 58000]

# Paddles
dit_in = Pin(7,  Pin.IN, Pin.PULL_UP)
dah_in = Pin(16, Pin.IN, Pin.PULL_UP)

# Rotary Encoder
clk = Pin(4,  Pin.IN, Pin.PULL_UP)
dt  = Pin(47, Pin.IN, Pin.PULL_UP)
sw  = Pin(45, Pin.IN, Pin.PULL_UP)
last_clk = clk.value()
rotary_hold_start = 0       # Measures how long the rotary encoder button is held
settings_menu_open = False  # Tracks if settings menu is open — starts closed

# External LED
led = Pin(1, Pin.OUT)

# SSD1306 OLED
i2c     = SoftI2C(scl=Pin(46), sda=Pin(8))
oled    = ssd1306.SSD1306_I2C(128, 64, i2c)
oled_gfx = gfx.GFX(128, 64, oled.pixel)

# SETTINGS MENU ##############################
settings_menu_items = [
    # Tuples of (display label, key). Headings skip selection and editing.
    ("MODAL CONFIG",  "heading"),
    ("Mode",          "mode"),
    ("BEHAVIOR",      "heading"),
    ("Keying Mode",   "keying_mode"),
    ("Volume",        "volume"),
    ("LED",           "led"),
    ("Decoding",      "decoding"),
    ("OTHER",         "heading"),
    ("About",         "about"),
    ("Reset",         "reset"),
]

settings = {
    # Default values for each editable setting
    "wpm":         10,
    "mode":         3,
    "volume":       5,
    "led":       True,
    "keying_mode":  0,
    "decoding":  True,
}

settings_menu_selected          = 0   # Currently highlighted menu item index
settings_menu_scroll            = 0   # Top-most visible menu item index (for scrolling)
settings_menu_line_height       = 10  # Pixels per menu row
settings_menu_max_visible_lines = 6   # How many rows fit on screen at once
settings_menu_in_scrollable_menu = 0  # Mode constant: browsing the menu
settings_menu_in_editing_menu    = 1  # Mode constant: editing a value
settings_menu_current_menu_mode  = settings_menu_in_scrollable_menu  # Start in scroll mode

about_scroll_offset = 0   # Current scroll position in the about screen (pixels)
about_scroll_speed  = 8   # Pixels scrolled per update call

# SOFTWARE ##############################

morse_oled_content = '/'  # Accumulates all keyed morse symbols for display and decoding
decoded_text       = ''   # Human-readable decoded output built from morse_oled_content
max_characters     = 16   # Max chars shown on OLED per row (SSD1306 is 16 chars wide at 8px)

# Sleep
sleep_enabled    = True         # Can be toggled in settings
device_sleeping  = False        # Tracks current sleep state
sleep_timeout_ms = 60000        # Idle milliseconds before sleeping (60 seconds)
last_input_time  = ticks_ms()   # Timestamp of last user activity

# <><><><><><><><><><><><><><><><><><><><><><>
# FUNCTIONS
# <><><><><><><><><><><><><><><><><><><><><><>

def do_a_dit():
    """Sound a dit, append '.' to morse content, then observe inter-element gap."""
    global morse_oled_content, last_morse_end_time
    buz.duty_u16(buz_volume)
    led.value(settings["led"])
    morse_oled_content = morse_oled_content + '.'
    draw_current_mode()
    sleep(dit_t)
    buz.duty_u16(0)
    led.value(0)
    sleep(gap_t)
    last_morse_end_time = ticks_ms()

def do_a_dah():
    """Sound a dah, append '-' to morse content, then observe inter-element gap."""
    global morse_oled_content, last_morse_end_time
    buz.duty_u16(buz_volume)
    led.value(settings["led"])
    morse_oled_content = morse_oled_content + '-'
    draw_current_mode()
    sleep(dah_t)
    buz.duty_u16(0)
    led.value(0)
    sleep(gap_t)
    last_morse_end_time = ticks_ms()

def draw_current_mode():
    """Dispatch display refresh to the draw function for the active mode."""
    current_mode = settings["mode"]
    if current_mode == "sandbox":
        draw_sandbox_mode(morse_oled_content)
    elif current_mode == "telegraph":
        draw_telegraph_mode(morse_oled_content)

def play_morse_string(morse_str):
    """
    Play back a pre-built morse string through the buzzer.

    Handles '.', '-', ' ' (letter break), and '/' (word break) symbols.
    Decodes and updates the display after each separator.

    Parameters
    ----------
    morse_str : str
        A morse string e.g. '... --- ...' to play back sequentially.

    Returns
    -------
    None
    """
    global morse_oled_content, decoded_text
    n = len(morse_str)
    for i, symbol in enumerate(morse_str):
        last_symbol = (i == n - 1)

        if symbol == '.':
            do_a_dit()
        elif symbol == '-':
            do_a_dah()
        elif symbol == ' ':
            # Letter break — decode the last letter and insert a space
            morse_decoder()
            morse_oled_content += ' '
            draw_sandbox_mode(morse_oled_content)
            sleep(letter_break_t)
        elif symbol == '/':
            # Word break — decode, insert slash, add decoded space
            morse_decoder()
            morse_oled_content += '/'
            decoded_text += ' '
            draw_sandbox_mode(morse_oled_content)
            sleep(word_break_t)

        # Treat the final symbol as a word break
        if last_symbol:
            morse_decoder()
            morse_oled_content += '/'
            decoded_text += ' '
            draw_sandbox_mode(morse_oled_content)
            sleep(word_break_t)

# DISPLAY HELPERS <><><><><><><><><><><><><><><><><><><><><><><><>

def draw_centered(text, center_x, y):
    """
    Draw text centred on a given x coordinate.

    Parameters
    ----------
    text : str
        String to render.
    center_x : int
        Pixel x position to centre the text around.
    y : int
        Pixel y position (top of text).
    """
    width = len(text) * 8
    x = center_x - (width // 2)
    oled.text(text, x, y)

def draw_right_aligned(text, right_x, y):
    """
    Draw text so its right edge sits at right_x.

    Parameters
    ----------
    text : str
        String to render.
    right_x : int
        Pixel x position of the right edge.
    y : int
        Pixel y position (top of text).
    """
    width = len(text) * 8  # 8 pixels per character
    x = right_x - width
    oled.text(text, x, y)

# MODE DRAW FUNCTIONS <><><><><><><><><><><><><><><><><><><><><><><><>

def draw_sandbox_mode(morse_oled_content=None):
    """
    Render the sandbox mode screen.

    Shows the last max_characters of morse content on row 1, and
    optionally the decoded text on row 2 if decoding is enabled.

    Parameters
    ----------
    morse_oled_content : str, optional
        Current morse string to display. Nothing is drawn if None.
    """
    oled.fill(0)
    if morse_oled_content is not None:
        oled.text('Morse:', 0, 0)
        draw_right_aligned((morse_oled_content[-max_characters:]), 128, 12)
        if settings["decoding"] == True:
            draw_right_aligned((decoded_text[-max_characters:]), 128, 24)
    oled.show()

def draw_telegraph_mode(morse_oled_content=None):
    """
    Render the telegraph mode screen.

    Same layout as sandbox but with a 'Telegraph:' heading.

    Parameters
    ----------
    morse_oled_content : str, optional
        Current morse string to display.
    """
    oled.fill(0)
    oled.text('Telegraph:', 0, 0)
    if morse_oled_content:
        draw_right_aligned(morse_oled_content[-max_characters:], 128, 12)
    if settings["decoding"] == True:
        draw_right_aligned(decoded_text[-max_characters:], 128, 24)
    oled.show()

# SETTINGS MENU <><><><><><><><><><><><><><><><><><><><><><><><>

def settings_menu_draw_menu():
    """
    Render the settings menu in either scrollable or editing mode.

    Scrollable mode shows a highlighted list of menu items.
    Editing mode shows the selected item's current value and allows changes.
    Headings are underlined and cannot be selected.
    """
    oled.fill(0)
    global settings_menu_scroll

    # EDITING MENU ########################
    if settings_menu_current_menu_mode == settings_menu_in_editing_menu:
        item  = settings_menu_items[settings_menu_selected]
        label = item[0]
        key   = item[1]

        if key not in ["heading", "about", "reset"]:
            value_of_currently_selected_menu_item = value_to_str(key, settings[key])
            draw_centered(label, 64, 18)
            draw_centered(value_of_currently_selected_menu_item, 64, 36)
        elif key == "about":
            draw_about_screen()
        elif key == "reset":
            device_reset()
        oled.show()
        return

    # SCROLLABLE SETTINGS MAIN MENU ########################
    # Keep heading visible when the first item beneath it is selected
    extra_heading_line = 0
    if settings_menu_selected == 1:
        extra_heading_line = 1

    if settings_menu_selected < settings_menu_scroll + extra_heading_line:
        settings_menu_scroll = settings_menu_selected - extra_heading_line
    elif settings_menu_selected >= settings_menu_scroll + settings_menu_max_visible_lines:
        settings_menu_scroll = settings_menu_selected - settings_menu_max_visible_lines + 1

    # Render only the visible window of items
    for i in range(settings_menu_scroll, min(settings_menu_scroll + settings_menu_max_visible_lines, len(settings_menu_items))):
        pixel_y = (i - settings_menu_scroll) * settings_menu_line_height
        if pixel_y + settings_menu_line_height > 64:
            continue  # Never clip past the bottom of the screen

        item  = settings_menu_items[i]
        label = item[0]
        key   = item[1]

        if key == "heading":
            oled.text(label, 4, pixel_y + 1, 1)
            oled_gfx.fill_rect(4, pixel_y + 9, len(label) * 8, 1, 1)  # Underline
        else:
            if i == settings_menu_selected:
                # Highlight selected item: white bar, black text
                oled_gfx.fill_rect(0, pixel_y + 1, 128, settings_menu_line_height - 2, 1)
                oled.text(label, 12, pixel_y + 1, 0)
            else:
                oled.text(label, 12, pixel_y + 1, 1)
    oled.show()

def draw_about_screen():
    """
    Render the scrolling about/credits screen.

    Scrolls upward on each call by about_scroll_speed pixels.
    Loops back to the start when the end of the credits is reached.
    """
    global about_scroll_offset
    oled.fill(0)
    credits = [
        "Scroll!",
        "", "", "",
        "Morse Keyer &",
        "Trainer",
        "",
        "Created by:",
        "Seth Hibpshman",
        "",
        "EENG 163",
        "Final Project",
        "",
        "Course",
        "Instructor:",
        "S. Rieseberg",
        "",
        "Software:",
        "- MicroPython",
        "- SSD1306 Lib",
        "  - GFX Lib",
        "- PyCharm",
        "- Thonny",
        "",
        "Special Thanks:",
        "- Supporters",
        "- Open Source",
        "  Community",
        "- Instructors",
        "- Family &",
        "  Friends",
        "",
        "License:",
        "GNU GPL v3",
        "", "", "",
        "The End <3 :)",
    ]

    total_height = len(credits) * 8
    y_start = 64 - 8 - about_scroll_offset  # Begin one line above the bottom edge

    for line_number, line_content in enumerate(credits):
        y = y_start + line_number * 8
        if -8 < y < 64:  # Only draw lines that are actually on screen
            oled.text(line_content, 0, y, 1)

    oled.show()
    about_scroll_offset += about_scroll_speed

    # Loop back to the beginning once all credits have scrolled past
    if about_scroll_offset > total_height + 64:
        about_scroll_offset = 0

# MORSE ENGINE <><><><><><><><><><><><><><><><><><><><><><><><>

def morse_decoder():
    """
    Decode the last morse letter in morse_oled_content and append it to decoded_text.

    Finds the most recent '/' or ' ' separator, extracts the symbol after it,
    and looks it up in morse_alph_dictionary. Appends '?' for unknown sequences.
    """
    global decoded_text
    index_last_slash = morse_oled_content.rfind('/')
    index_last_space = morse_oled_content.rfind(' ')
    last_break_index = max(index_last_slash, index_last_space)

    last_morse_letter = morse_oled_content[last_break_index + 1:].strip()

    if last_morse_letter:
        if morse_alph_dictionary.get(last_morse_letter):
            decoded_text = decoded_text + morse_alph_dictionary[last_morse_letter]
        else:
            decoded_text = decoded_text + '?'  # Unknown sequence

def gap_checker():
    """
    Detect letter and word gaps between paddle presses and insert separators.

    Monitors idle time since the last paddle activity. If idle exceeds
    letter_break_t a space is inserted; if it further exceeds word_break_t
    the space is upgraded to a '/'.
    """
    global morse_oled_content, idle_start_time, letter_space_happened, word_space_happened, decoded_text

    if dit_val == False and dah_val == False:
        # No paddle activity — start or continue counting idle time
        if idle_start_time == 0:
            idle_start_time = current_time
        idle_time = ticks_diff(current_time, idle_start_time)

        # Insert letter space after letter_break_t milliseconds
        if idle_time >= int(letter_break_t * 1000) and letter_space_happened == False:
            morse_decoder()
            morse_oled_content = morse_oled_content + ' '
            draw_sandbox_mode(morse_oled_content)
            letter_space_happened = True
            word_space_happened   = False

        # Upgrade letter space to word break after word_break_t milliseconds
        if letter_space_happened == True and word_space_happened == False:
            if idle_time >= int((word_break_t) * 1000):
                if morse_oled_content and morse_oled_content[-1] == ' ':
                    morse_oled_content = morse_oled_content[:-1] + '/'
                    decoded_text = decoded_text + ' '
                draw_sandbox_mode(morse_oled_content)
                word_space_happened = True
    else:
        # Paddle active — reset all gap tracking
        idle_start_time       = 0
        letter_space_happened = False
        word_space_happened   = False

def keying_handler(dit_val, dah_val, current_time):
    """
    Dispatch paddle presses to the correct keying mode logic.

    Supported modes: Iambic A, Iambic B, Ultimatic, Straight Key.
    Also tracks hold start times and release times for each paddle.

    Parameters
    ----------
    dit_val : bool
        True if the dit paddle is currently pressed.
    dah_val : bool
        True if the dah paddle is currently pressed.
    current_time : int
        Current ticks_ms() value.
    """
    global last_d
    global bth_hld, bth_hld_prev
    global dit_hold_start_time, dah_hold_start_time
    global dit_held, dah_held
    global dit_release_time, dah_release_time

    keying_mode = keying_modes[settings["keying_mode"]]

    # BUTTON STATE TRACKING ############################################
    if dit_val == True and dit_held == False:
        dit_hold_start_time = current_time
        dit_held = True
    elif dit_val == False and dit_held == True:
        dit_held = False
        dit_release_time = current_time

    if dah_val == True and dah_held == False:
        dah_hold_start_time = current_time
        dah_held = True
    elif dah_val == False and dah_held == True:
        dah_held = False
        dah_release_time = current_time

    # IAMBIC A ##############################
    if keying_mode == 'Iambic A':
        if dit_val and dah_val:
            if last_d == 'dah':
                do_a_dit(); last_d = 'dit'
            else:
                do_a_dah(); last_d = 'dah'
        elif dit_val:
            do_a_dit(); last_d = 'dit'
        elif dah_val:
            do_a_dah(); last_d = 'dah'

    # IAMBIC B ##############################
    elif keying_mode == 'Iambic B':
        if dit_val and dah_val:
            bth_hld = True
            if last_d == 'dah':
                do_a_dit(); last_d = 'dit'
            else:
                do_a_dah(); last_d = 'dah'
        elif bth_hld_prev == True:
            if last_d == 'dah':
                do_a_dit(); last_d = 'dit'
            else:
                do_a_dah(); last_d = 'dah'
        elif dit_val:
            do_a_dit(); last_d = 'dit'
        elif dah_val:
            do_a_dah(); last_d = 'dah'

        bth_hld_prev = bth_hld
        bth_hld = False

    # ULTIMATIC #############################
    elif keying_mode == 'Ultimatic':
        if dit_val and dah_val:
            if dit_hold_start_time < dah_hold_start_time:
                do_a_dah()
            elif dit_hold_start_time > dah_hold_start_time:
                do_a_dit()
        elif dit_val:
            do_a_dit(); last_d = 'dit'
        elif dah_val:
            do_a_dah(); last_d = 'dah'

    # STRAIGHT KEY ##########################
    elif keying_mode == 'Straight Key':
        if dit_val or dah_val:
            buz.duty_u16(buz_volume)
            led.value(settings["led"])
        else:
            buz.duty_u16(0)
            led.value(0)

def core_engine_update(dit_val, dah_val, current_time):
    """
    Run one tick of the morse engine: keying then gap detection.

    Parameters
    ----------
    dit_val : bool
        True if the dit paddle is currently pressed.
    dah_val : bool
        True if the dah paddle is currently pressed.
    current_time : int
        Current ticks_ms() value.
    """
    keying_handler(dit_val, dah_val, current_time)
    gap_checker()

# MODE HANDLERS <><><><><><><><><><><><><><><><><><><><><><><><><><><><><><><>

def sandbox_mode(dit_val, dah_val, current_time):
    """Run the engine and refresh the sandbox display."""
    core_engine_update(dit_val, dah_val, current_time)
    draw_sandbox_mode(morse_oled_content)

def training_mode(dit_val, dah_val, current_time):
    """Run the engine and refresh the training display. (Scoring TBD)"""
    core_engine_update(dit_val, dah_val, current_time)
    draw_sandbox_mode(morse_oled_content)

def telegraph_mode(dit_val, dah_val, current_time):
    """
    Run the engine, transmit morse_oled_content over UART, and refresh display.

    Sends the full current morse string as a UTF-8 newline-terminated
    message on every loop tick for the receiving STM32 LCD display.
    """
    global morse_oled_content, decoded_text, last_sent_morse
    core_engine_update(dit_val, dah_val, current_time)
    uart_message = f'{morse_oled_content}\n'
    uart.write(uart_message.encode('utf-8'))
    last_sent_morse = morse_oled_content
    draw_telegraph_mode(morse_oled_content)

def debug_mode(dit_val, dah_val, current_time):
    """
    Display live diagnostic information — paddle state, encoder pins, memory, clock.

    Parameters
    ----------
    dit_val : bool
        Current dit paddle state.
    dah_val : bool
        Current dah paddle state.
    current_time : int
        Current ticks_ms() value.
    """
    oled.fill(0)

    heading = 'DEBUG MODE:'
    oled.text(f"{heading}", 0, 0)
    oled_gfx.fill_rect(4, 9, len(heading) * 8, 1, 1)  # Underline

    dit_state = "ON" if dit_val else "OFF"
    dah_state = "ON" if dah_val else "OFF"
    oled.text(f"DIT/DAH: {dit_state}/{dah_state}", 0, 12)
    oled.text(f"ENC C:{clk.value()} D:{dt.value()} S:{sw.value()}", 0, 22)

    free = gc.mem_free()
    used = gc.mem_alloc()
    oled.text(f"F:{free // 1024:03d}kB", 0, 44)
    oled.text(f"U:{used // 1024:03d}kB", 64, 44)
    oled.text(f"CLK: {current_time} ms", 0, 56)
    oled.show()

# SETTINGS HELPERS <><><><><><><><><><><><><><><><><><><><><><><><>

def value_to_str(key, menu_value):
    """
    Convert a settings value to a human-readable string for the editing menu.

    Parameters
    ----------
    key : str
        The settings dictionary key (e.g. 'mode', 'volume').
    menu_value : any
        The current value stored for that key.

    Returns
    -------
    str
        Display string for the editing menu (e.g. 'Enabled', 'Sandbox').
    """
    if key == "mode":
        return modes[menu_value]
    if key == "keying_mode":
        return keying_modes[menu_value]
    if key in ["led", "decoding"]:
        return "Enabled" if menu_value else "Disabled"
    return str(menu_value)
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

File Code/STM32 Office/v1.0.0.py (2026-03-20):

"""
Morse RX Display - STM32 + ILI9341 LCD
=======================================
Receives morse code strings over UART and displays the last 20 characters
on a 240x320 ILI9341 LCD. Line 1 is a static label; line 2 updates on RX.

Hardware:
    - STM32 microcontroller (MicroPython)
    - ILI9341 LCD via SPI5
    - UART1 (PA9=TX, PA10=RX) at 115200 baud

Classes:
    DisplayDriver  -- manages LCD rendering for the two-line layout
    MorseReceiver  -- handles UART receive, decoding, and display updates
    
Author: Seth Hibpshman
Course: EENG 163 Final Project
License: GNU GPL v3
"""

from machine import Pin, UART, SPI
from time import sleep
from lcd9341 import LCD9341, color565
from xfglcd_font import XglcdFont


# Display constants <><><><><><><><><><><><><><><><><><><><><><><><>

char_width    = 12
char_height   = 24
display_chars = 20          # max chars across the 240 px screen (240 / 12 = 20)

text_x  = 0
line1_y = 0                 # static label row (y pixel offset)
line2_y = char_height       # dynamic morse row (one char-height below label)

text_w  = char_width * display_chars    # 240 px - full screen width
text_h  = char_height                   # 24 px - one character row height

bg_color     = color565(0,   0,   0)
fg_color     = color565(255, 255, 255)

# Hardware init <><><><><><><><><><><><><><><><><><><><><><><><>

spi      = SPI(5, baudrate=10_000_000)
lcd      = LCD9341(spi, dc=Pin('PD13'), cs=Pin('PC2'), rst=Pin('PC11'))
unispace = XglcdFont('fonts/Unispace12x24.c', 12, 24)


# Classes <><><><><><><><><><><><><><><><><><><><><><><><>

class DisplayDriver:
    """
    Manages the two-line ILI9341 LCD layout.

    Line 1 is a static label drawn once at init.
    Line 2 is a 20-character dynamic field, redrawn only when content changes.

    Attributes
    ----------
    lcd : LCD9341
        The LCD driver instance.
    font : XglcdFont
        The font used for all text rendering.
    last_drawn : str or None
        The last string written to line 2; used to skip redundant redraws.

    Methods
    -------
    update(text):
        Update line 2 with the last 20 characters of text.
    """

    def __init__(self, lcd, font, label):
        """
        Initialise the display, clear it, and draw the static label.

        Parameters
        ----------
        lcd : LCD9341
            Initialised LCD driver object.
        font : XglcdFont
            Font object for rendering text.
        label : str
            Static string drawn once on line 1 (e.g. "Morse RX:").
        """
        self.lcd        = lcd
        self.font       = font
        self.last_drawn = None

        # Clear screen and draw the static label - never redrawn after this
        self.lcd.clear(bg_color)
        self.lcd.draw_text(text_x, line1_y, label, self.font, fg_color)

    def update(self, text):
        """
        Redraw line 2 with the last 20 characters of text.

        Skips all SPI activity if the visible content has not changed,
        minimising scanline artifacts on the slow ILI9341 refresh.

        Parameters
        ----------
        text : str
            The full morse string received so far; only the trailing
            display_chars characters are rendered.

        Returns
        -------
        None
        """
        # Take last 20 chars and pad with spaces to erase leftover glyphs
        snippet = text[-display_chars:]
        while len(snippet) < display_chars:
            snippet = snippet + " "

        # Dirty-check - skip redraw if nothing visible has changed
        if snippet == self.last_drawn:
            return
        self.last_drawn = snippet

        # Clear only the line 2 bounding box, then draw new text
        for row in range(text_h):
            self.lcd.draw_hline(text_x, line2_y + row, text_w, bg_color)
        self.lcd.draw_text(text_x, line2_y, snippet, self.font, fg_color)


class MorseReceiver:
    """
    Reads newline-terminated morse strings from a UART and forwards them
    to a DisplayDriver instance for rendering.

    Attributes
    ----------
    uart : UART
        The MicroPython UART object to read from.
    display : DisplayDriver
        The display instance that renders received messages.
    rx_buf : bytes
        Internal accumulation buffer for incoming UART bytes.
    morse_content : str
        The most recently received (non-empty) morse string.

    Methods
    -------
    poll():
        Read available UART bytes, extract complete lines, and update display.
    """

    def __init__(self, uart, display):
        """
        Bind a UART and a DisplayDriver together.

        Parameters
        ----------
        uart : UART
            Initialised MicroPython UART object (e.g. UART(1, 115200)).
        display : DisplayDriver
            Initialised DisplayDriver that will render received strings.
        """
        self.uart          = uart
        self.display       = display
        self.rx_buf        = b""
        self.morse_content = ""

    def poll(self):
        """
        Non-blocking UART poll - call repeatedly from the main loop.

        Appends any available bytes to the internal buffer, then extracts
        and processes every complete newline-terminated line. Silently
        discards lines that cannot be decoded as UTF-8 or are blank.

        Returns
        -------
        None
        """
        if not self.uart.any():
            return

        self.rx_buf += self.uart.read()

        # Process every complete line in the buffer
        while b"\n" in self.rx_buf:
            line, self.rx_buf = self.rx_buf.split(b"\n", 1)
            try:
                decoded = line.decode('utf-8').strip()
            except UnicodeError:
                continue        # drop malformed bytes

            if decoded:
                self.morse_content = decoded
                self.display.update(self.morse_content)


# Entry point <><><><><><><><><><><><><><><><><><><><><><><><>

display  = DisplayDriver(lcd, unispace, "Morse RX:")
receiver = MorseReceiver(UART(1, 115200), display)

# Brief boot confirmation on line 2, then clear it before live RX begins
display.update("LCD OK")
sleep(1)
display.update("")

# Main loop - poll UART continuously at 10 ms intervals
while True:
    receiver.poll()
    sleep(0.01)
